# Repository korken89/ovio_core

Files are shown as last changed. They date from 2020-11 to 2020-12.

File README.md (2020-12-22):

# Open Visual Inertial Odometry (OVIO) Core

## Current status

Work in progress. PCB have arrived for v1.0 of the board and bring-up has started.

### Issues with v1.0 hardware (fixed in v1.1)

* The MOSFET is 180 degrees rotated.
* The MOSI/MISO lines for the SPI flash are swapped.
* The CS line of the SPI flash is connected to the wrong pad on the FPGA, flashing and loading bitstream from v1.0 hardware will not work.

Images from the assembly and results here: https://twitter.com/korken89/status/1341126909485342721

## Motivation

Aim: A "low cost" Visual Inertial Odometry accelerator.

A project to try out different vision processing pipelines, for Visual Inertial Odometry (VIO), on the ECP5 FPGA. As far as I know, the open hardware landscape of VIO cameras is slim to non-existent. Especially for systems which perform a majority of the pre-processing in the camera.

Things such as image convolutions, FAST corners, multi-scale images, non-maximum suppression, image gradients, etc, are extremely well suited for FPGA implementation.

Why do it on a PC? Let it run the actual Kalman Filter / MHE / nonlinear optimizer, which the FPGA is not well suited for.

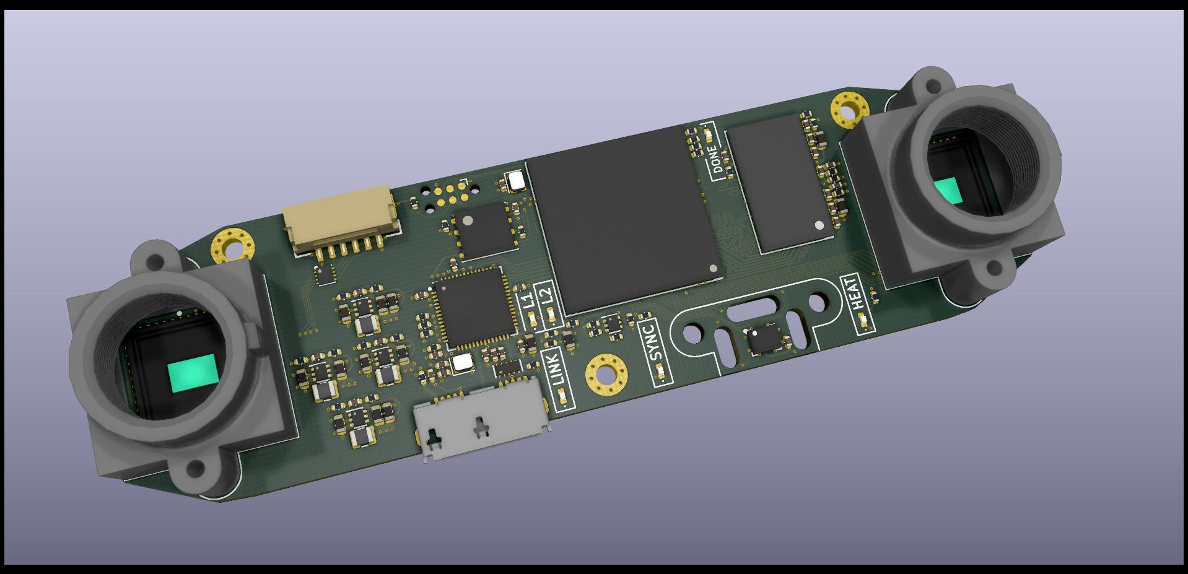
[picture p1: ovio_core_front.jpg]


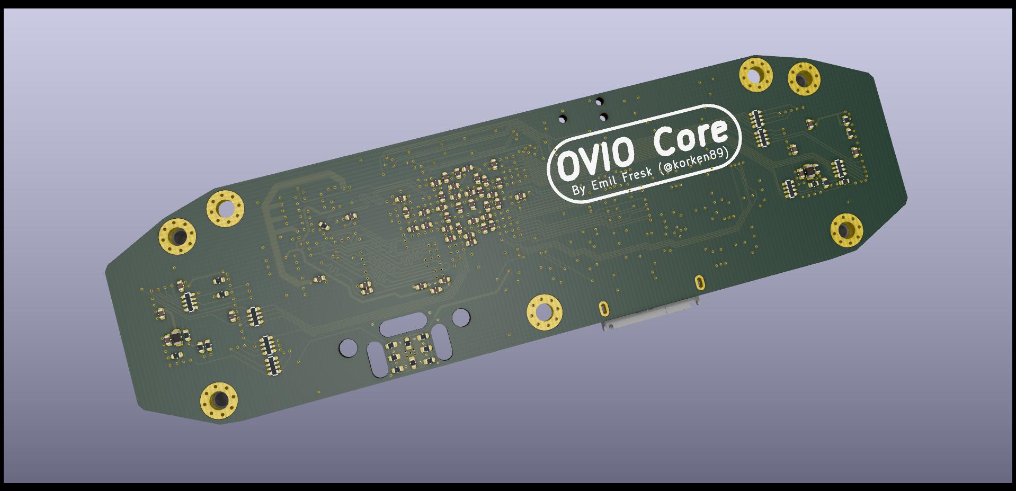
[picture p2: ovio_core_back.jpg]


## Specs

* Lattice ECP5U-85, design is pin-compatible to all the smaller versions
* 1 GBit DDR3 memory
* FT600 USB 3.0 FIFO with 200 MB/s transfer rate
* 2x MT9V034 cameras with tight hardware synchronization control loops (center of integration of both cameras are aligned to IMU measurements)
* Temperature stabilized ST ISM330DHC IMU (16g / 4000 dps max)

## Do you want one?

Previous projects has been made on Xilinx FPGAs, however the high cost of their FPGAs never allowed for trying to distribute a camera. Now it is expected that the hardware cost for this system should be sub 100 Euros, even with the largest ECP5 FPGA.

If there is interest for acquiring a camera, contact me (via any medium) and we'll figure something out.

## Lenses and lens holder

* http://www.m12lenses.com/2-1mm-F2-2-Board-Lens-p/pt-02120.htm
* http://www.m12lenses.com/M12-Lens-Holder-Plastic-p/pt-lh001p.htm

## Contributors

- Emil Fresk ([@korken89](https://github.com/korken89/))

## License

This hardware is open source.

TODO: Find a proper license

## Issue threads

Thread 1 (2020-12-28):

Simplification of power rails

korken89, 2020-12-28:
One thing I have realized with my design is that having DC/DC converters for all rails was probably overkill.
I could have gone with LDOs for the 1.8V and 2.5V rails, and feed them from the 3.3V DC/DC to reduce the BOM and size of the PSU area.

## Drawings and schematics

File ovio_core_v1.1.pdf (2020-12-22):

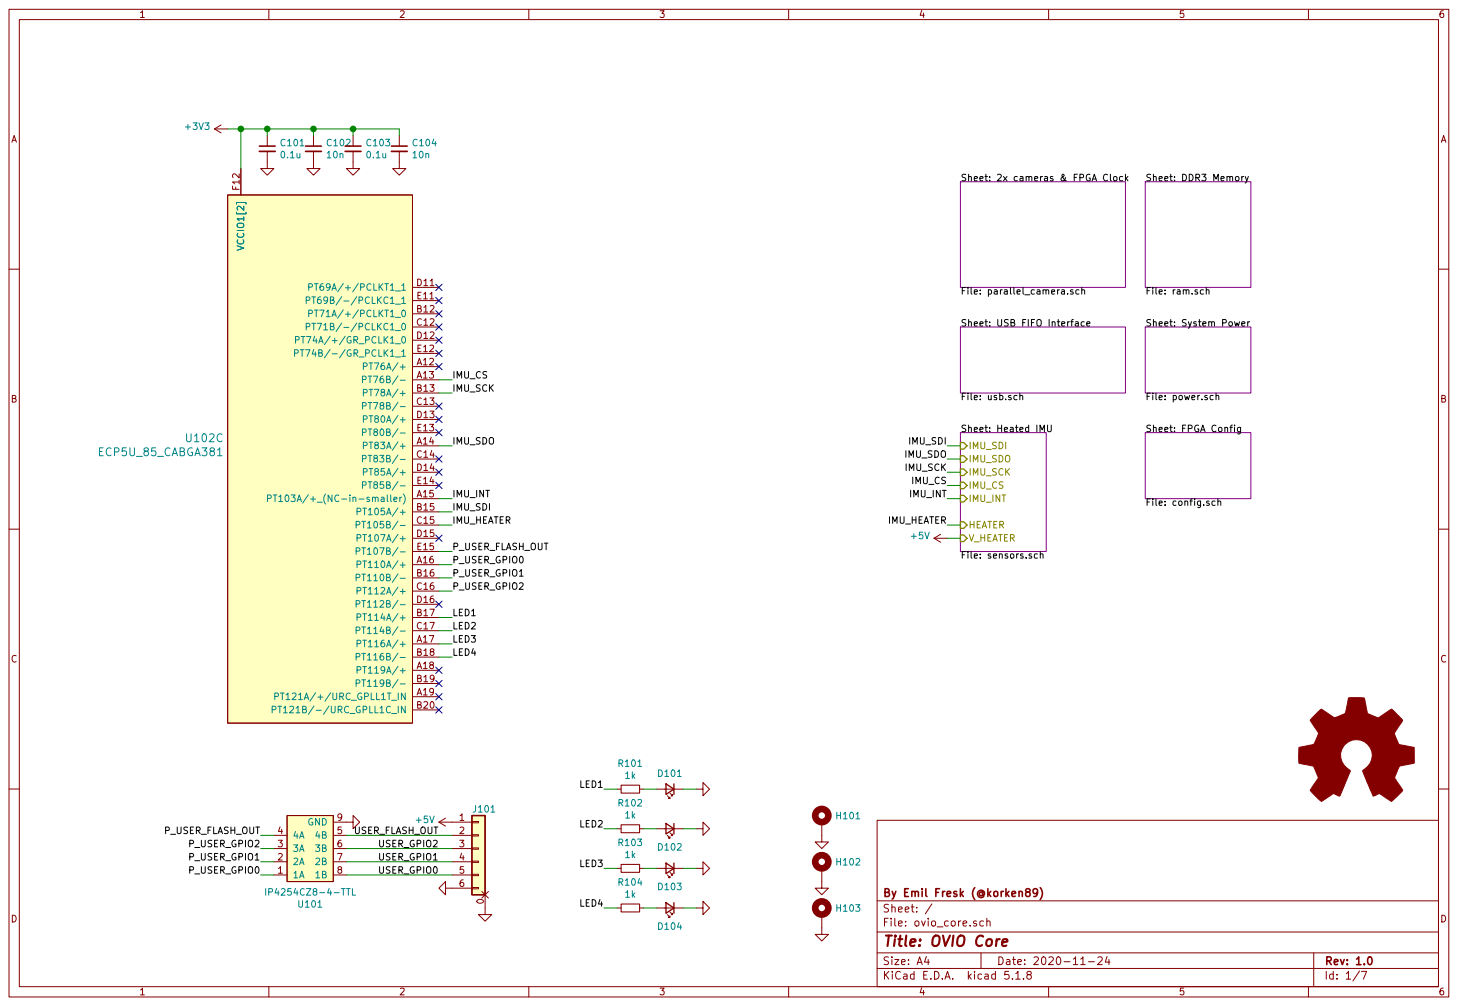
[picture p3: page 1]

Sheet: DDR3 Memory File: ram.sch Sheet: USB FIFO Interface File: usb.sch Sheet: 2x cameras & FPGA Clock File: parallel_camera.sch

File: ovio_core.sch Sheet: / By Emil Fresk (@korken89)

Id: 1/7 Title: OVIO Core

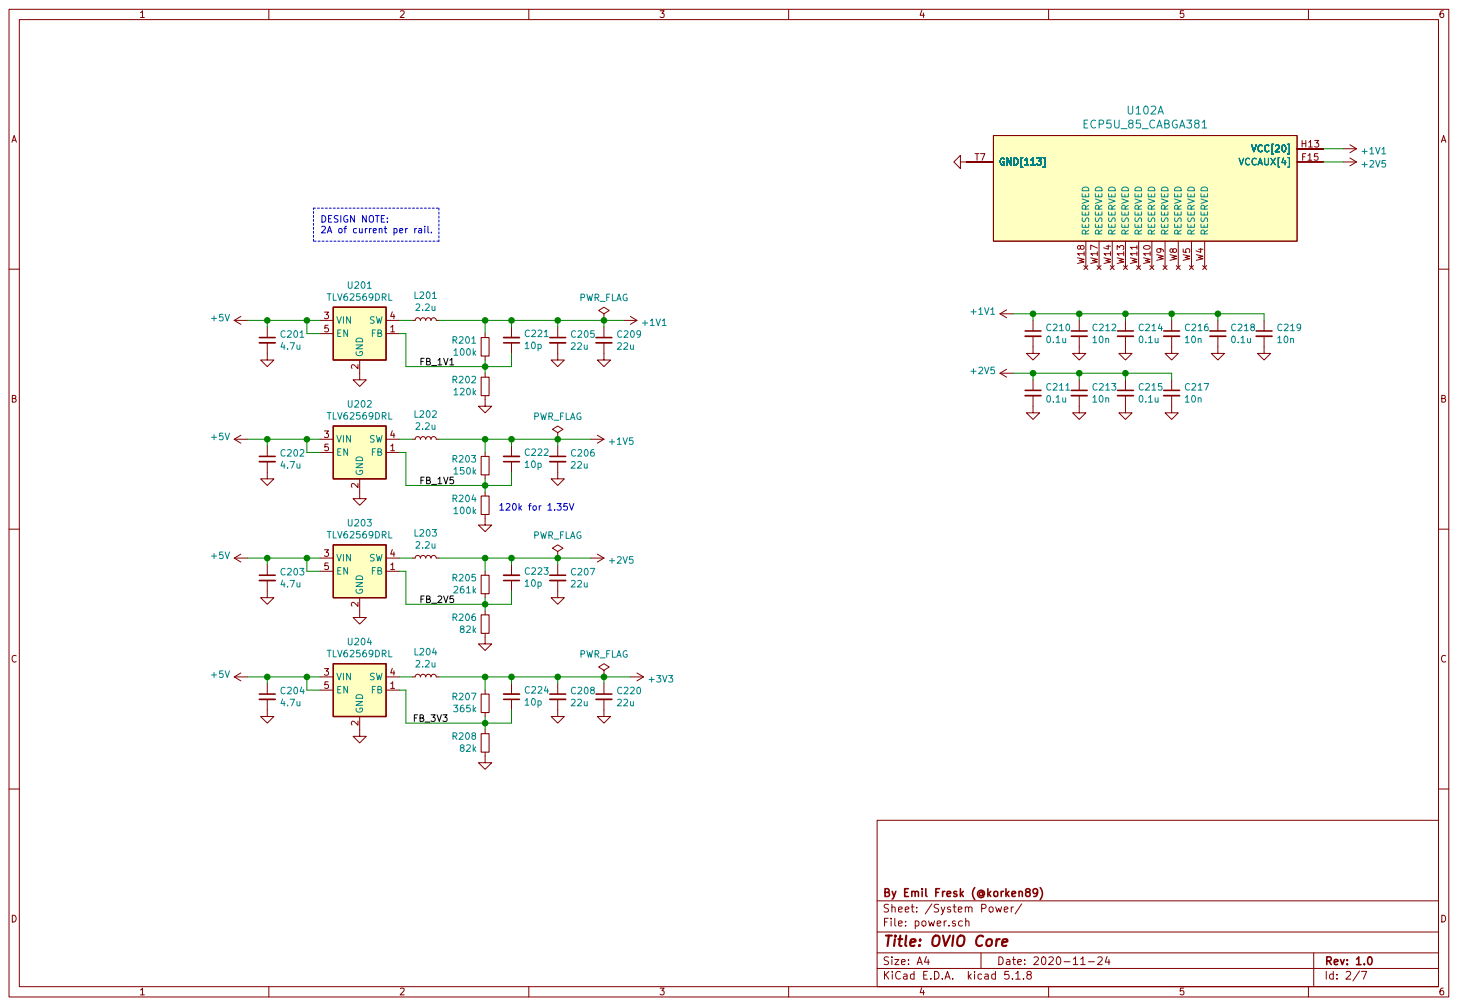
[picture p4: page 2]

By Emil Fresk (@korken89)
Sheet: /System Power/
File: power.sch
Id: 2/7 Title: OVIO Core

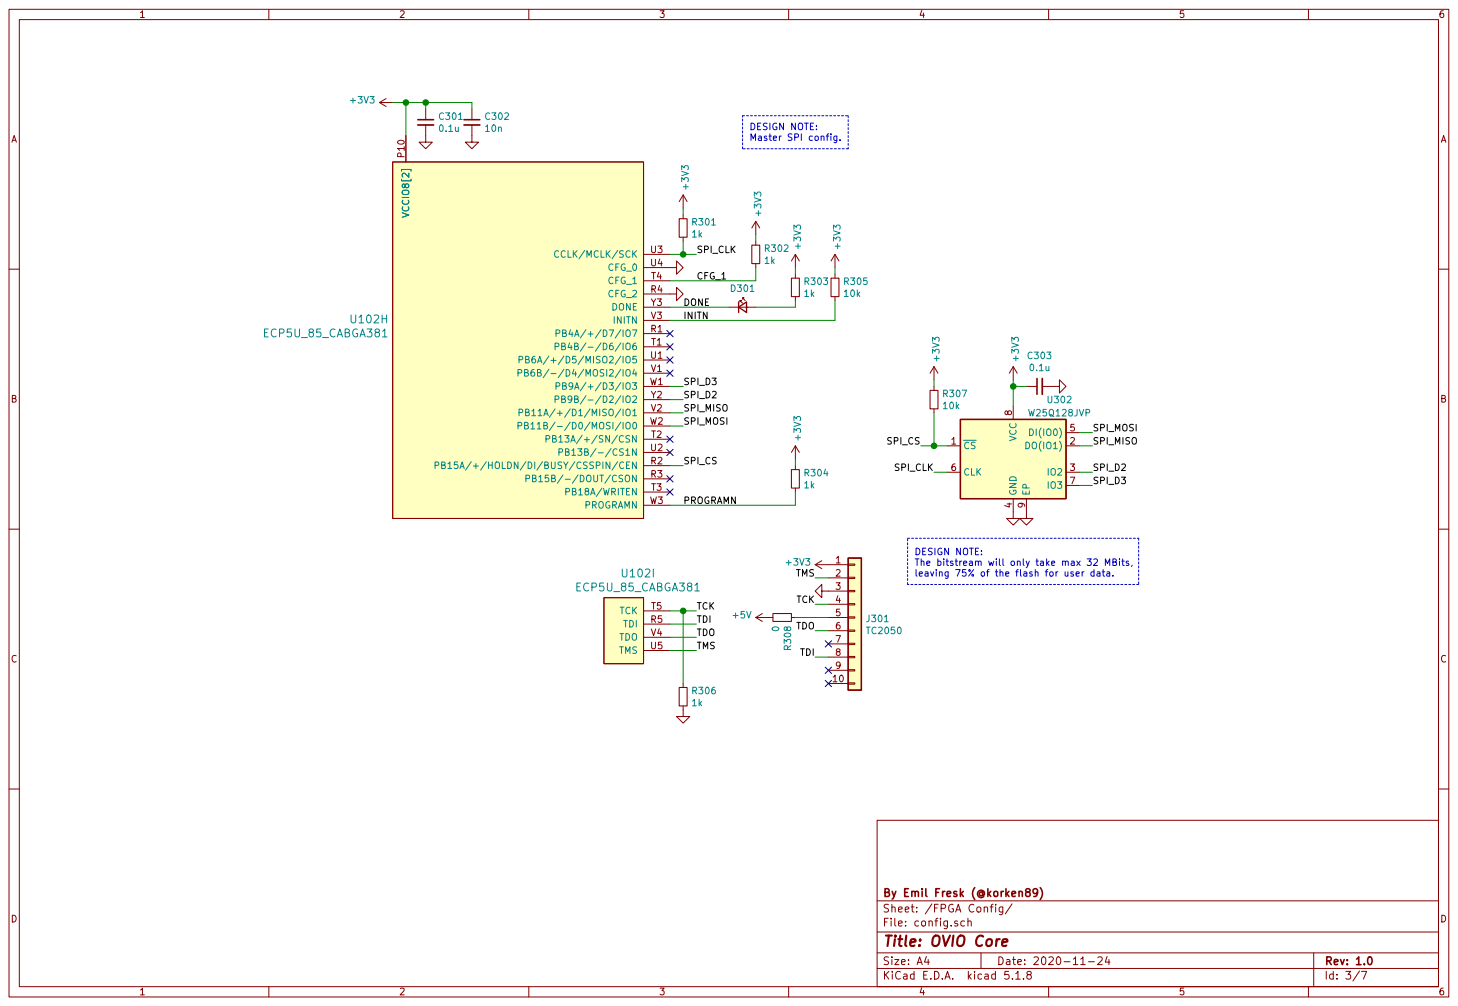
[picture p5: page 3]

leaving 75% of the flash for user data. DESIGN NOTE: Master SPI config.

Sheet: /FPGA Config/
File: config.sch
Id: 3/7 Title: OVIO Core

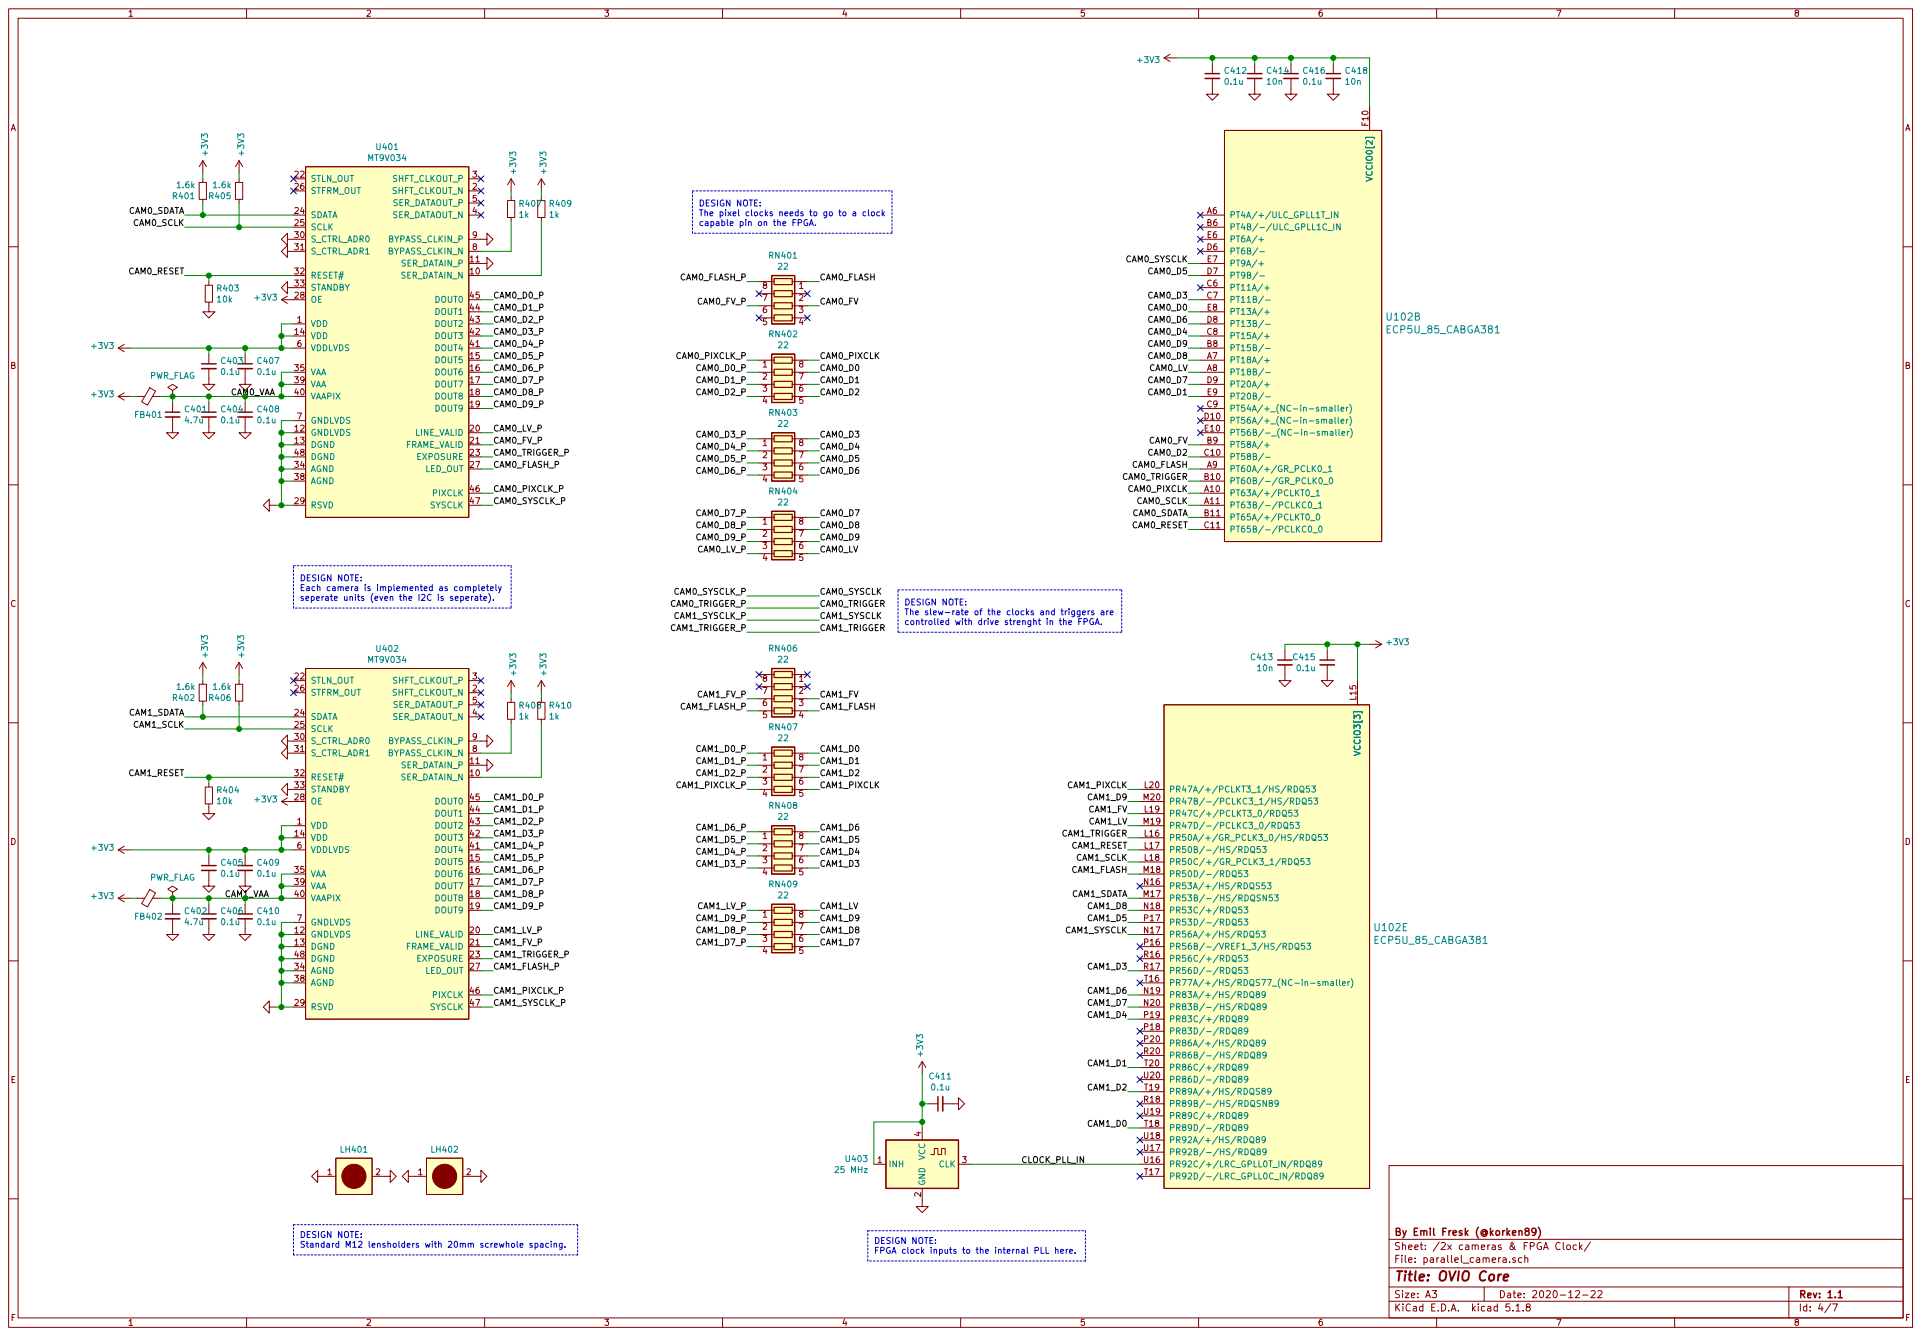
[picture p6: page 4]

controlled with drive strenght in the FPGA. DESIGN NOTE: The pixel clocks needs to go to a clock

capable pin on the FPGA. DESIGN NOTE: Each camera is implemented as completely

seperate units (even the I2C is seperate).

File: parallel_camera.sch Sheet: /2x cameras & FPGA Clock/ By Emil Fresk (@korken89)

Id: 4/7 Title: OVIO Core

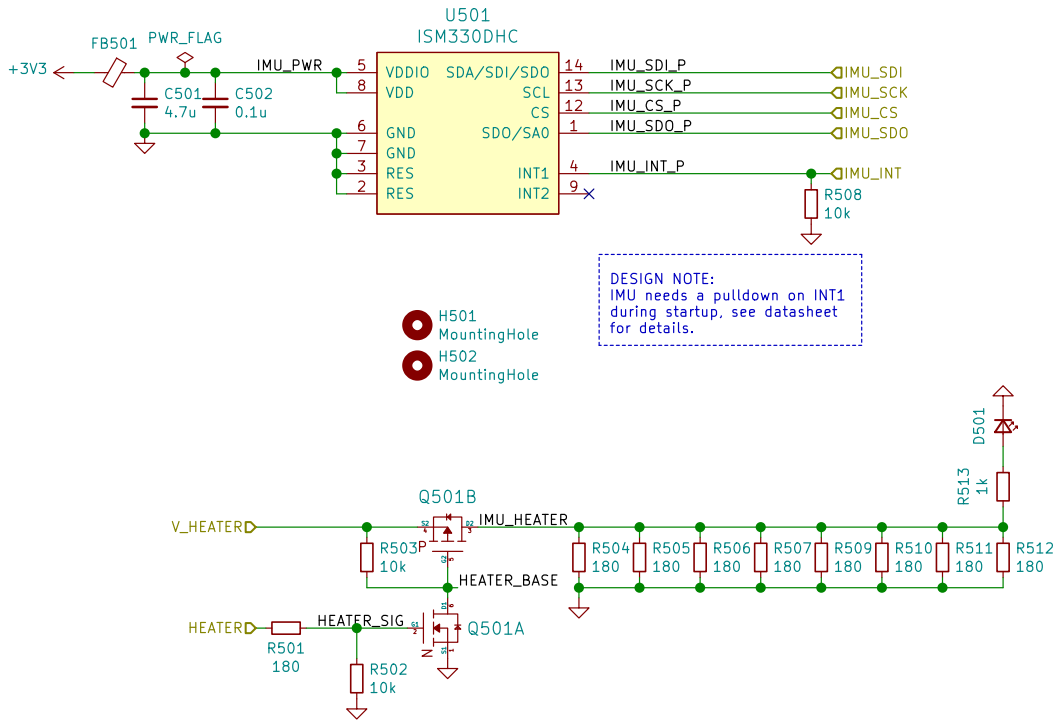
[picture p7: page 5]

IMU_SCK_P
IMU_CS_P
IMU_SDO_P
File: sensors.sch Sheet: /Heated IMU/ By Emil Fresk (@korken89) R507

DESIGN NOTE:
IMU needs a pulldown on INT1
during startup, see datasheet
for details.

Id: 5/7 Title: OVIO Core

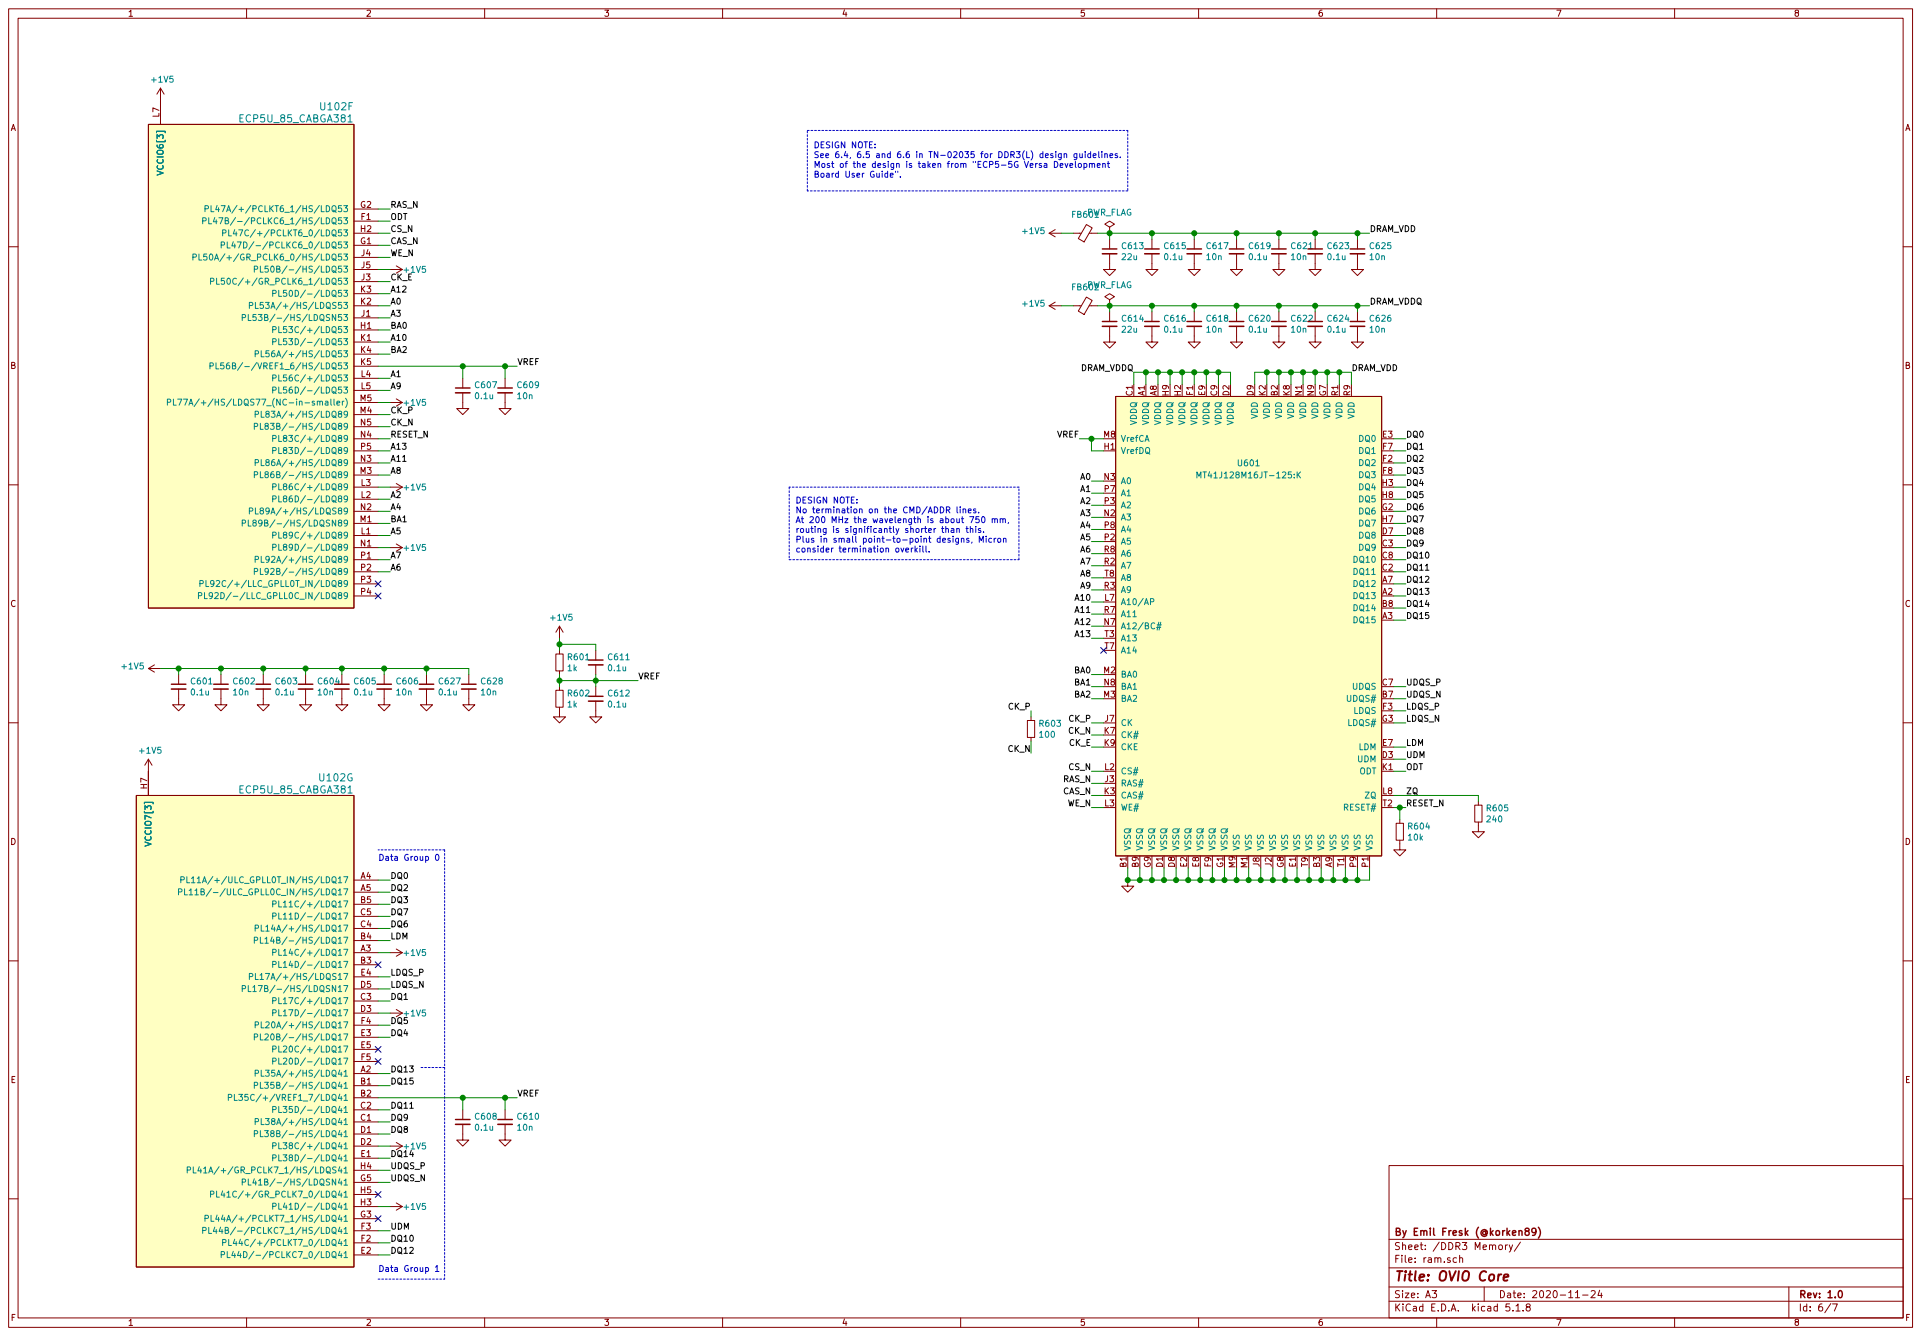
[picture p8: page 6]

DESIGN NOTE: See 6.4, 6.5 and 6.6 in TN-02035 for DDR3(L) design guidelines.

Most of the design is taken from "ECP5-5G Versa Development Board User Guide". DESIGN NOTE: No termination on the CMD/ADDR lines. At 200 MHz the wavelength is about 750 mm,

routing is significantly shorter than this.
Plus in small point-to-point designs, Micron
consider termination overkill.

By Emil Fresk (@korken89)
File: ram.sch Sheet: /DDR3 Memory/
Id: 6/7 Title: OVIO Core

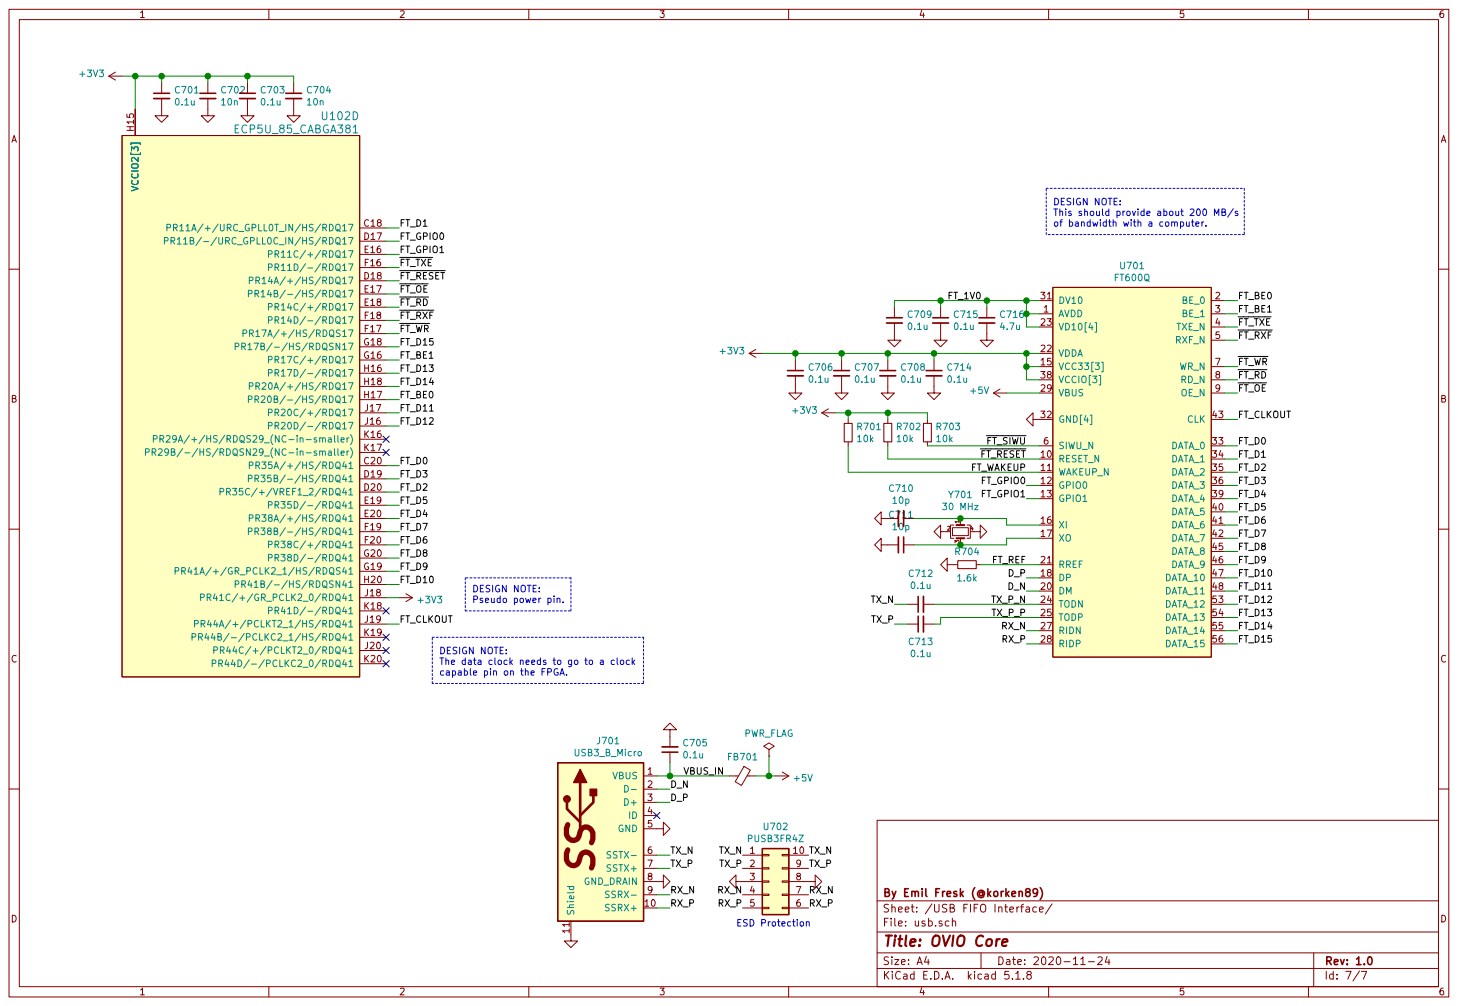
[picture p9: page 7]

of bandwidth with a computer. DESIGN NOTE: The data clock needs to go to a clock

capable pin on the FPGA.

File: usb.sch Sheet: /USB FIFO Interface/ By Emil Fresk (@korken89)

Id: 7/7 Title: OVIO Core

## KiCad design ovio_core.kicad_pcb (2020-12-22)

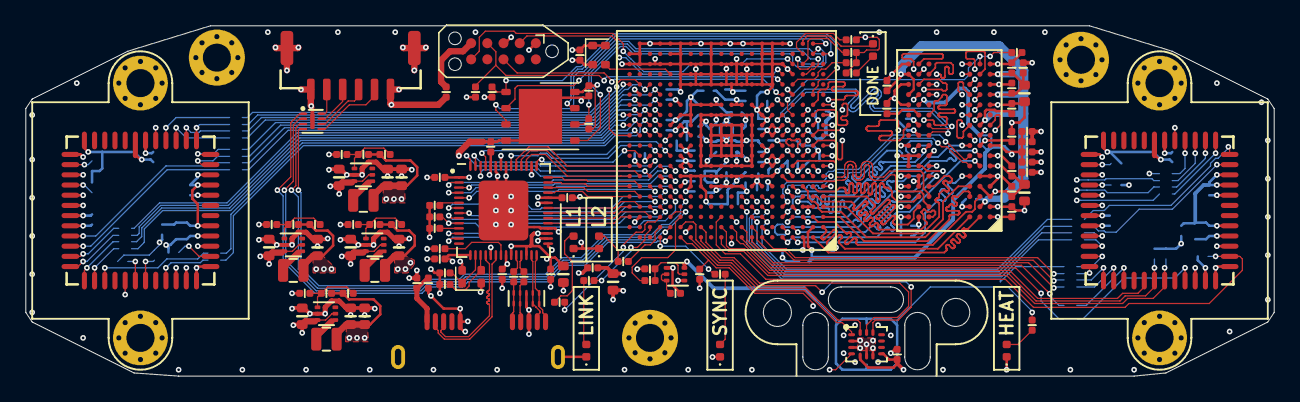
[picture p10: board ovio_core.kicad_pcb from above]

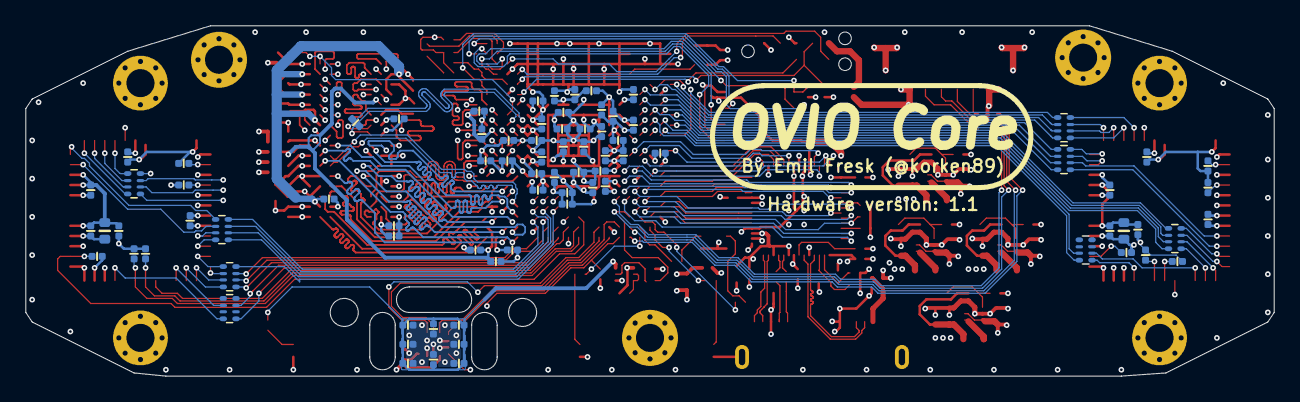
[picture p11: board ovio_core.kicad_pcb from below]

Board: 6 copper layers, 98.0 x 27.5 mm, 196 parts (81 on the bottom side), 224 nets.

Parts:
C101, C103, C210, C211, C214, C215, C218, C301, C303, C403, C404, C405, C406, C407, C408, C409, C410, C411, C412, C415, C416, C502, C601, C603, C605, C607, C608, C611, C612, C615, C616, C619, C620, C623, C624, C627, C701, C703, C705, C706, C707, C708, C709, C712, C713, C714, C715: 0.1u; C_0402
C102, C104, C212, C213, C216, C217, C219, C302, C413, C414, C418, C602, C604, C606, C609, C610, C617, C618, C621, C622, C625, C626, C628, C702, C704: 10n; C_0402
C201, C202, C203, C204, C401, C402, C501, C716: 4.7u; C_0603
C205, C206, C207, C208, C209, C220, C613, C614: 22u; C_0603
C221, C222, C223, C224, C710, C711: 10p; C_0402
D101, D102, D103, D104, D301, D501: LED_Small; LED_0402_1005Metric
FB401, FB402, FB501, FB601, FB602, FB701: Ferrite_Bead_Small; R_0402
H101, H102, H103: MountingHole_Pad; MountingHole_2.2mm_M2_Pad_Via
H501, H502: MountingHole; MountingHole_2.2mm_M2
J101: Conn_01x06; SM06B-GHS-TB
J301: TC2050; Tag-Connect_TC2050-IDC-NL_2x05_P1.27mm_Vertical
J701: USB3_B_Micro; AMPHENOL-GSB343K33HR
L201, L202, L203, L204: 2.2u; L_0806_2016Metric
LH401, LH402: lens_holder; m12_20mm
Q501: NTZD3155C; SOT-563
R101, R102, R103, R104, R301, R302, R303, R304, R306, R407, R408, R409, R410, R513, R601, R602: 1k; R_0402
R201, R204: 100k; R_0402
R202: 120k; R_0402
R203: 150k; R_0402
R205: 261k; R_0402
R206, R208: 82k; R_0402
R207: 365k; R_0402
R305, R307, R403, R404, R502, R503, R508, R604, R701, R702, R703: 10k; R_0402
R308: 0; R_0402
R401, R402, R405, R406, R704: 1.6k; R_0402
R501, R504, R505, R506, R507, R509, R510, R511, R512: 180; R_0402
R603: 100; R_0402
R605: 240; R_0402
RN401, RN402, RN403, RN404, RN406, RN407, RN408, RN409: 22; R_Array_Convex_4x0402
U101: IP4254CZ8-4-TTL; UDFN-8-1EP_1.7x1.35mm_P0.4mm_EP0.4x1.2mm
U102: ECP5U_85_CABGA381; caBGA_381_17x17
U201, U202, U203, U204: TLV62569DRL; SOT-563
U302: W25Q128JVP; WSON-8-1EP_6x5mm_P1.27mm_EP3.4x4.3mm
U401, U402: MT9V034
U403: 25 MHz; Crystal_4Pin_2.0x1.6mm
U501: ISM330DHC; LGA-14-2.5x3
U601: MT41J128M16JT-125:K; BGA-96_8.0x14.0mm_DDR16
U701: FT600Q; QFN-56-1EP_7x7mm_P0.4mm_EP5.7x5.7mm_FT600
U702: PUSB3FR4Z; DFN-10-1.0x2.5mm_P0.5mm
Y701: 30 MHz; Crystal_4Pin_2.0x1.6mm

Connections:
+1V1: C205.1, C209.1, C210.1, C212.1, C214.1, C216.1, C218.1, C219.1, C221.2, L201.2, R201.2, U102.H8, U102.H9, U102.H10, U102.H11, U102.H12, U102.H13, U102.J8, U102.J13, U102.K8, U102.K13, U102.L8, U102.L13, U102.M8, U102.M13, U102.N8, U102.N9, U102.N10, U102.N11, U102.N12, U102.N13
+1V5: C206.1, C222.2, C601.1, C602.1, C603.1, C604.1, C605.1, C606.1, C611.1, C627.1, C628.1, FB601.1, FB602.1, L202.2, R203.2, R601.1, U102.A3, U102.D2, U102.D3, U102.H3, U102.H6, U102.H7, U102.J5, U102.J6, U102.L3, U102.L6, U102.L7, U102.M5, U102.M6, U102.N1
+2V5: C207.1, C211.1, C213.1, C215.1, C217.1, C223.2, L203.2, R205.2, U102.F6, U102.F15, U102.P6, U102.P15
+3V3: C101.1, C102.1, C103.1, C104.1, C208.1, C220.1, C224.2, C301.1, C302.1, C303.1, C403.1, C405.1, C407.1, C409.1, C411.1, C412.1, C413.1, C414.1, C415.1, C416.1, C418.1, C701.1, C702.1, C703.1, C704.1, C706.1, C707.1, C708.1, C714.1, FB401.2, FB402.2, FB501.2, J301.1, L204.2, R207.2, R301.1, R302.1, R303.1, R304.1, R305.1, R307.1, R401.2, R402.2, R405.2, R406.2, R407.1, R408.1, R409.1, R410.1, R701.1, R702.1, R703.1, U102.F9, U102.F10, U102.F11, U102.F12, U102.H14, U102.H15, U102.J15, U102.J18, U102.L14, U102.L15, U102.M15, U102.P9, U102.P10, U302.8, U401.1, U401.6, U401.14, U401.28, U402.1, U402.6, U402.14, U402.28, U403.1, U403.4, U701.15, U701.19, U701.22, U701.30, U701.38, U701.44, U701.52
+5V: C201.1, C202.1, C203.1, C204.1, FB701.1, J101.1, Q501.4, R308.2, R503.1, U201.3, U201.5, U202.3, U202.5, U203.3, U203.5, U204.3, U204.5, U701.29
/2x cameras & FPGA Clock/CAM0_D0: RN402.7, U102.E8
/2x cameras & FPGA Clock/CAM0_D0_P: RN402.2, U401.45
/2x cameras & FPGA Clock/CAM0_D1: RN402.6, U102.E9
/2x cameras & FPGA Clock/CAM0_D1_P: RN402.3, U401.44
/2x cameras & FPGA Clock/CAM0_D2: RN402.5, U102.C10
/2x cameras & FPGA Clock/CAM0_D2_P: RN402.4, U401.43
/2x cameras & FPGA Clock/CAM0_D3: RN403.8, U102.C7
/2x cameras & FPGA Clock/CAM0_D3_P: RN403.1, U401.42
/2x cameras & FPGA Clock/CAM0_D4: RN403.7, U102.C8
/2x cameras & FPGA Clock/CAM0_D4_P: RN403.2, U401.41
/2x cameras & FPGA Clock/CAM0_D5: RN403.6, U102.D7
/2x cameras & FPGA Clock/CAM0_D5_P: RN403.3, U401.15
/2x cameras & FPGA Clock/CAM0_D6: RN403.5, U102.D8
/2x cameras & FPGA Clock/CAM0_D6_P: RN403.4, U401.16
/2x cameras & FPGA Clock/CAM0_D7: RN404.8, U102.D9
/2x cameras & FPGA Clock/CAM0_D7_P: RN404.1, U401.17
/2x cameras & FPGA Clock/CAM0_D8: RN404.7, U102.A7
/2x cameras & FPGA Clock/CAM0_D8_P: RN404.2, U401.18
/2x cameras & FPGA Clock/CAM0_D9: RN404.6, U102.B8
/2x cameras & FPGA Clock/CAM0_D9_P: RN404.3, U401.19
/2x cameras & FPGA Clock/CAM0_FLASH: RN401.1, U102.A9
/2x cameras & FPGA Clock/CAM0_FLASH_P: RN401.8, U401.27
/2x cameras & FPGA Clock/CAM0_FV: RN401.3, U102.B9
/2x cameras & FPGA Clock/CAM0_FV_P: RN401.6, U401.21
/2x cameras & FPGA Clock/CAM0_LV: RN404.5, U102.A8
/2x cameras & FPGA Clock/CAM0_LV_P: RN404.4, U401.20
/2x cameras & FPGA Clock/CAM0_PIXCLK: RN402.8, U102.A10
/2x cameras & FPGA Clock/CAM0_PIXCLK_P: RN402.1, U401.46
/2x cameras & FPGA Clock/CAM0_RESET: R403.1, U102.C11, U401.32
/2x cameras & FPGA Clock/CAM0_SCLK: R405.1, U102.A11, U401.25
/2x cameras & FPGA Clock/CAM0_SDATA: R401.1, U102.B11, U401.24
/2x cameras & FPGA Clock/CAM0_SYSCLK: U102.E7, U401.47
/2x cameras & FPGA Clock/CAM0_TRIGGER: U102.B10, U401.23
/2x cameras & FPGA Clock/CAM0_VAA: C401.1, C404.1, C408.1, FB401.1, U401.35, U401.39, U401.40
/2x cameras & FPGA Clock/CAM1_D0: RN407.8, U102.T18
/2x cameras & FPGA Clock/CAM1_D0_P: RN407.1, U402.45
/2x cameras & FPGA Clock/CAM1_D1: RN407.7, U102.T20
/2x cameras & FPGA Clock/CAM1_D1_P: RN407.2, U402.44
/2x cameras & FPGA Clock/CAM1_D2: RN407.6, U102.T19
/2x cameras & FPGA Clock/CAM1_D2_P: RN407.3, U402.43
/2x cameras & FPGA Clock/CAM1_D3: RN408.5, U102.R17
/2x cameras & FPGA Clock/CAM1_D3_P: RN408.4, U402.42
/2x cameras & FPGA Clock/CAM1_D4: RN408.6, U102.P19
/2x cameras & FPGA Clock/CAM1_D4_P: RN408.3, U402.41
/2x cameras & FPGA Clock/CAM1_D5: RN408.7, U102.P17
/2x cameras & FPGA Clock/CAM1_D5_P: RN408.2, U402.15
/2x cameras & FPGA Clock/CAM1_D6: RN408.8, U102.N19
/2x cameras & FPGA Clock/CAM1_D6_P: RN408.1, U402.16
/2x cameras & FPGA Clock/CAM1_D7: RN409.5, U102.N20
/2x cameras & FPGA Clock/CAM1_D7_P: RN409.4, U402.17
/2x cameras & FPGA Clock/CAM1_D8: RN409.6, U102.N18
/2x cameras & FPGA Clock/CAM1_D8_P: RN409.3, U402.18
/2x cameras & FPGA Clock/CAM1_D9: RN409.7, U102.M20
/2x cameras & FPGA Clock/CAM1_D9_P: RN409.2, U402.19
/2x cameras & FPGA Clock/CAM1_FLASH: RN406.4, U102.M18
/2x cameras & FPGA Clock/CAM1_FLASH_P: RN406.5, U402.27
/2x cameras & FPGA Clock/CAM1_FV: RN406.3, U102.L19
/2x cameras & FPGA Clock/CAM1_FV_P: RN406.6, U402.21
/2x cameras & FPGA Clock/CAM1_LV: RN409.8, U102.M19
/2x cameras & FPGA Clock/CAM1_LV_P: RN409.1, U402.20
/2x cameras & FPGA Clock/CAM1_PIXCLK: RN407.5, U102.L20
/2x cameras & FPGA Clock/CAM1_PIXCLK_P: RN407.4, U402.46
/2x cameras & FPGA Clock/CAM1_RESET: R404.1, U102.L17, U402.32
/2x cameras & FPGA Clock/CAM1_SCLK: R406.1, U102.L18, U402.25
/2x cameras & FPGA Clock/CAM1_SDATA: R402.1, U102.M17, U402.24
/2x cameras & FPGA Clock/CAM1_SYSCLK: U102.N17, U402.47
/2x cameras & FPGA Clock/CAM1_TRIGGER: U102.L16, U402.23
/2x cameras & FPGA Clock/CAM1_VAA: C402.1, C406.1, C410.1, FB402.1, U402.35, U402.39, U402.40
/2x cameras & FPGA Clock/CLOCK_PLL_IN: U102.U16, U403.3
/DDR3 Memory/A0: U102.K2, U601.N3
/DDR3 Memory/A1: U102.L4, U601.P7
/DDR3 Memory/A2: U102.L2, U601.P3
/DDR3 Memory/A3: U102.J1, U601.N2
/DDR3 Memory/A4: U102.N2, U601.P8
/DDR3 Memory/A5: U102.L1, U601.P2
/DDR3 Memory/A6: U102.P2, U601.R8
/DDR3 Memory/A7: U102.P1, U601.R2
/DDR3 Memory/A8: U102.M3, U601.T8
/DDR3 Memory/A9: U102.L5, U601.R3
/DDR3 Memory/A10: U102.K1, U601.L7
/DDR3 Memory/A11: U102.N3, U601.R7
/DDR3 Memory/A12: U102.K3, U601.N7
/DDR3 Memory/A13: U102.P5, U601.T3
/DDR3 Memory/BA0: U102.H1, U601.M2
/DDR3 Memory/BA1: U102.M1, U601.N8
/DDR3 Memory/BA2: U102.K4, U601.M3
/DDR3 Memory/CAS_N: U102.G1, U601.K3
/DDR3 Memory/CK_E: U102.J3, U601.K9
/DDR3 Memory/CK_N: R603.2, U102.N5, U601.K7
/DDR3 Memory/CK_P: R603.1, U102.M4, U601.J7
/DDR3 Memory/CS_N: U102.H2, U601.L2
/DDR3 Memory/DQ0: U102.A4, U601.E3
/DDR3 Memory/DQ1: U102.C3, U601.F7
/DDR3 Memory/DQ2: U102.A5, U601.F2
/DDR3 Memory/DQ3: U102.B5, U601.F8
/DDR3 Memory/DQ4: U102.E3, U601.H3
/DDR3 Memory/DQ5: U102.F4, U601.H8
/DDR3 Memory/DQ6: U102.C4, U601.G2
/DDR3 Memory/DQ7: U102.C5, U601.H7
/DDR3 Memory/DQ8: U102.D1, U601.D7
/DDR3 Memory/DQ9: U102.C1, U601.C3
/DDR3 Memory/DQ10: U102.F2, U601.C8
/DDR3 Memory/DQ11: U102.C2, U601.C2
/DDR3 Memory/DQ12: U102.E2, U601.A7
/DDR3 Memory/DQ13: U102.A2, U601.A2
/DDR3 Memory/DQ14: U102.E1, U601.B8
/DDR3 Memory/DQ15: U102.B1, U601.A3
/DDR3 Memory/DRAM_VDD: C613.1, C615.1, C617.1, C619.1, C621.1, C623.1, C625.1, FB601.2, U601.B2, U601.D9, U601.G7, U601.K2, U601.K8, U601.N1, U601.N9, U601.R1, U601.R9
/DDR3 Memory/DRAM_VDDQ: C614.1, C616.1, C618.1, C620.1, C622.1, C624.1, C626.1, FB602.2, U601.A1, U601.A8, U601.C1, U601.C9, U601.D2, U601.E9, U601.F1, U601.H2, U601.H9
/DDR3 Memory/LDM: U102.B4, U601.E7
/DDR3 Memory/LDQS_N: U102.D5, U601.G3
/DDR3 Memory/LDQS_P: U102.E4, U601.F3
/DDR3 Memory/ODT: U102.F1, U601.K1
/DDR3 Memory/RAS_N: U102.G2, U601.J3
/DDR3 Memory/RESET_N: R604.1, U102.N4, U601.T2
/DDR3 Memory/UDM: U102.F3, U601.D3
/DDR3 Memory/UDQS_N: U102.G5, U601.B7
/DDR3 Memory/UDQS_P: U102.H4, U601.C7
/DDR3 Memory/VREF: C607.1, C608.1, C609.1, C610.1, C611.2, C612.1, R601.2, R602.1, U102.B2, U102.K5, U601.H1, U601.M8
/DDR3 Memory/WE_N: U102.J4, U601.L3
/DDR3 Memory/ZQ: R605.1, U601.L8
/FPGA Config/CFG_1: R302.2, U102.T4
/FPGA Config/DONE: D301.1, U102.Y3
/FPGA Config/INITN: R305.2, U102.V3
/FPGA Config/PROGRAMN: R304.2, U102.W3
/FPGA Config/SPI_CLK: R301.2, U102.U3, U302.6
/FPGA Config/SPI_CS: R307.2, U102.R2, U302.1
/FPGA Config/SPI_D2: U102.Y2, U302.3
/FPGA Config/SPI_D3: U102.W1, U302.7
/FPGA Config/SPI_MISO: U102.V2, U302.2
/FPGA Config/SPI_MOSI: U102.W2, U302.5
/FPGA Config/TCK: J301.4, R306.1, U102.T5
/FPGA Config/TDI: J301.8, U102.R5
/FPGA Config/TDO: J301.6, U102.V4
/FPGA Config/TMS: J301.2, U102.U5
/Heated IMU/HEATER_BASE: Q501.5, Q501.6, R503.2
/Heated IMU/HEATER_SIG: Q501.2, R501.1, R502.1
/Heated IMU/IMU_HEATER: Q501.3, R504.1, R505.1, R506.1, R507.1, R509.1, R510.1, R511.1, R512.1, R513.1
/Heated IMU/IMU_PWR: C501.1, C502.1, FB501.1, U501.5, U501.8
/IMU_CS: U102.A13, U501.12
/IMU_HEATER: R501.2, U102.C15
/IMU_INT: R508.1, U102.A15, U501.4
/IMU_SCK: U102.B13, U501.13
/IMU_SDI: U102.B15, U501.14
/IMU_SDO: U102.A14, U501.1
/LED1: R101.1, U102.B17
/LED2: R102.1, U102.C17
/LED3: R103.1, U102.A17
/LED4: R104.1, U102.B18
/P_USER_FLASH_OUT: U101.4, U102.E15
/P_USER_GPIO0: U101.1, U102.A16
/P_USER_GPIO1: U101.2, U102.B16
/P_USER_GPIO2: U101.3, U102.C16
/System Power/FB_1V1: C221.1, R201.1, R202.2, U201.1
/System Power/FB_1V5: C222.1, R203.1, R204.2, U202.1
/System Power/FB_2V5: C223.1, R205.1, R206.2, U203.1
/System Power/FB_3V3: C224.1, R207.1, R208.2, U204.1
/USB FIFO Interface/D_N: J701.2, U701.20
/USB FIFO Interface/D_P: J701.3, U701.18
/USB FIFO Interface/FT_BE0: U102.H17, U701.2
/USB FIFO Interface/FT_BE1: U102.G16, U701.3
/USB FIFO Interface/FT_CLKOUT: U102.J19, U701.43
/USB FIFO Interface/FT_D0: U102.C20, U701.33
/USB FIFO Interface/FT_D1: U102.C18, U701.34
/USB FIFO Interface/FT_D2: U102.D20, U701.35
/USB FIFO Interface/FT_D3: U102.D19, U701.36
/USB FIFO Interface/FT_D4: U102.E20, U701.39
/USB FIFO Interface/FT_D5: U102.E19, U701.40
/USB FIFO Interface/FT_D6: U102.F20, U701.41
/USB FIFO Interface/FT_D7: U102.F19, U701.42
/USB FIFO Interface/FT_D8: U102.G20, U701.45
/USB FIFO Interface/FT_D9: U102.G19, U701.46
/USB FIFO Interface/FT_D10: U102.H20, U701.47
/USB FIFO Interface/FT_D11: U102.J17, U701.48
/USB FIFO Interface/FT_D12: U102.J16, U701.53
/USB FIFO Interface/FT_D13: U102.H16, U701.54
/USB FIFO Interface/FT_D14: U102.H18, U701.55
/USB FIFO Interface/FT_D15: U102.G18, U701.56
/USB FIFO Interface/FT_GPIO0: U102.D17, U701.12
/USB FIFO Interface/FT_GPIO1: U102.E16, U701.13
/USB FIFO Interface/FT_REF: R704.1, U701.21
/USB FIFO Interface/FT_WAKEUP: R701.2, U701.11
/USB FIFO Interface/RX_N: J701.9, U701.27, U702.4, U702.7
/USB FIFO Interface/RX_P: J701.10, U701.28, U702.5, U702.6
/USB FIFO Interface/TX_N: C712.1, J701.6, U702.1, U702.10
/USB FIFO Interface/TX_P: C713.1, J701.7, U702.2, U702.9
/USB FIFO Interface/TX_P_N: C712.2, U701.24
/USB FIFO Interface/TX_P_P: C713.2, U701.25
/USB FIFO Interface/VBUS_IN: C705.1, FB701.2, J701.1
/USB FIFO Interface/~FT_OE: U102.E17, U701.9
/USB FIFO Interface/~FT_RD: U102.E18, U701.8
/USB FIFO Interface/~FT_RESET: R702.2, U102.D18, U701.10
/USB FIFO Interface/~FT_RXF: U102.F18, U701.5
/USB FIFO Interface/~FT_SIWU: R703.2, U701.6
/USB FIFO Interface/~FT_TXE: U102.F16, U701.4
/USB FIFO Interface/~FT_WR: U102.F17, U701.7
/USER_FLASH_OUT: J101.2, U101.5
/USER_GPIO0: J101.5, U101.8
/USER_GPIO1: J101.4, U101.7
/USER_GPIO2: J101.3, U101.6
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

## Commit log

2020-11-15 Schematic, general layout and DDR3 routing done
    [config.sch, ovio_core.kicad_pcb, ovio_core.sch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]
2020-11-15 USB 3.0 chip layout
    [config.sch, ovio_core.kicad_pcb, ovio_core.sch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]
2020-11-16 Fixed libs
    [ovio_core.sch, ram.sch, usb.sch]
2020-11-16 USB fifo routed
    [ovio_core.kicad_pcb, ovio_core.sch, parallel_camera.sch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]
2020-11-16 More routing
    [config.sch, ovio_core.kicad_pcb, ovio_core.sch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]
2020-11-22 Camera 1, JTAG, SPI Flash routed
    [config.sch, ovio_core.kicad_pcb, ovio_core.sch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]
2020-11-23 DRC pass, routing finished
    [ovio_core.kicad_pcb, ovio_core.sch, parallel_camera.sch]
2020-11-24 Added comments and fixed ERC erros
    [config.sch, ovio_core.kicad_pcb, ovio_core.sch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]
2020-11-24 Added info to sheets, added hardware version to board
    [config.sch, ovio_core.kicad_pcb, ovio_core.sch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]
2020-11-24 Minor skew fix on HS USB lines
    [ovio_core.kicad_pcb]
2020-11-24 Minor fixes
    [ovio_core.kicad_pcb]
2020-11-28 Now with TC2050 for programming
    [config.sch, ovio_core.kicad_pcb]
2020-11-28 Small cleanup for PCB order
    [ovio_core.kicad_pcb]
2020-12-22 Updated from v1.0 build
    [config.sch, ovio_core.kicad_pcb, ovio_core.sch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]
